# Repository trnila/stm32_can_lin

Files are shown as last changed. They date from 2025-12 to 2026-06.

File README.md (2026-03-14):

# STM32 Triple CAN/LIN USB bridge
STM32G4xx firmware written in Rust using the Embassy framework that bridges CAN-FD buses to Linux via USB using the `gs_usb` driver and socketCAN interface.

- 3x CAN-FD channels
    - configurable 120Ω termination resistor

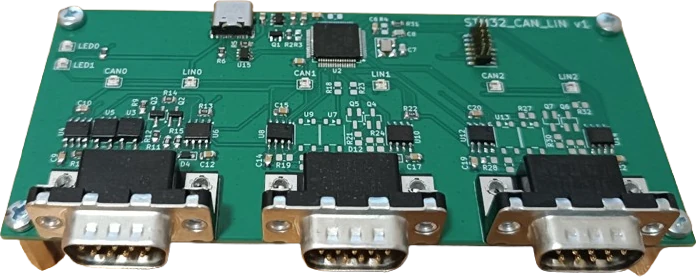
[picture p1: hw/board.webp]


## Build & flash & run
Install Rust via [rustup.rs](https://rustup.rs/).

Set `nSWBOOT0` to 0 using STM32CubeProgrammer for the first time, then connect the debugger and flash the device:
```sh
$ cargo run --release
```

Three socketCAN interfaces will appear, for example as `can0`, `can1`, and `can2`.
You can configure them using `ip` command:
```sh
$ sudo ip link set can0 type can bitrate 500000
$ sudo ip link set can0 up
```

After that, you can start sending and receiving CAN frames:
```sh
$ candump can0
$ cansend can0 123#abcd
```

## Configuration
All configurations must be done while the interface is in the `down` state.
```sh
$ sudo ip link set can0 down
```
After the configuration, bring the interface `up`.

### CAN-FD mode and data bitrate
Set CAN to 500 Kbps and CAN-FD to 1 Mbps:
```sh
$ sudo ip link set can0 type can bitrate 500000 fd on dbitrate 1000000
```

### 120Ω termination resistor
Termination resistor can be enabled in configuration mode via:
```sh
$ sudo ip link set can0 down
$ sudo ip link set can0 type can bitrate 500000 termination 120
$ sudo ip link set can0 up
```

### Persistent interface names
Configure udev rules (`/etc/udev/rules.d/91-scan.rules`) for persistent interface names:
```
SUBSYSTEM=="net", ENV{ID_SERIAL}=="trnila_STM32_CAN_LIN_1", ATTR{dev_id}=="0x0", NAME="scan0"
SUBSYSTEM=="net", ENV{ID_SERIAL}=="trnila_STM32_CAN_LIN_1", ATTR{dev_id}=="0x1", NAME="scan1"
SUBSYSTEM=="net", ENV{ID_SERIAL}=="trnila_STM32_CAN_LIN_1", ATTR{dev_id}=="0x2", NAME="scan2"
```
and then reload `sudo udevadm control --reload-rules` and re-plug the device.

## Test
Install following dependencies:
- uv
- [can-utils](https://github.com/linux-can/can-utils)

Next, connect the DUT's `can0` interface to the tester's `can1_0` interface, and so on. Then run:
```sh
$ CAN_IFACES=0:can0:can1_0,1:can1:can1_1,2:can2:can0_0 ./hw_test.py
```

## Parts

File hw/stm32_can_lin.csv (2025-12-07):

Reference | Qty | Value | DNP | Exclude from BOM | Exclude from Board | manf#
C1 | 1 | 10uF
C2,C4,C5 | 3 | 1uF
C3,C6,C9,C10,C12,C14,C15,C17,C19,C20,C22,C24 | 12 | 100nF
C7,C8 | 2 | 9pF
C11,C16,C21 | 3 | 4.7nF
C13,C18,C23 | 3 | 1nF | DNP
D1,D2,D6,D7,D8,D9,D13,D14 | 8 | WS2812B-2020 |  |  |  | WS2812B-2020
D3,D10,D15 | 3 | NUP2105L |  |  |  | NUP2105L
D4,D11,D16 | 3 | D |  |  |  | BAS321,115
D5,D12,D17 | 3 | ESD1LIN24 |  |  |  | ESD1LIN24
H1,H2,H3,H4 | 4 | MountingHole |  | Excluded from BOM
J1 | 1 | USB_C_Receptacle_USB2.0_16P |  |  |  | USB4105-GF-A-120
J2 | 1 | STM32 SWD |  |  |  | FTSH-107-01-L-DV-K-A-P-TR
J3,J4,J5 | 3 | DE9_Pins_MountingHoles |  |  |  | LD09P33E4GX00LF
Q1 | 1 | BSS123 |  |  |  | BSS123
Q2,Q4,Q6 | 3 | YJL2301F |  |  |  | YJL2301F
Q3,Q5,Q7 | 3 | MMBT2222A |  |  |  | MMBT2222A
R1,R2,R11,R20,R29 | 5 | 10k
R3,R13,R22,R31 | 4 | 47k
R4 | 1 | 10k | DNP
R5,R6 | 2 | 5.1k
R8,R10,R17,R19,R26,R28 | 6 | 56R
R9,R18,R27 | 3 | 6k8
R12,R21,R30 | 3 | 120R
R14,R23,R32 | 3 | 3k3
R15,R24,R33 | 3 | 1k
U1 | 1 | AP2112K-3.3 |  |  |  | AP2112K-3.3TRG1
U2 | 1 | STM32G474RETx |  |  |  | STM32G474RET6
U3,U5,U7,U9,U11,U13 | 6 | EPR411A064000EZ |  |  |  | EPR411A064000EZ
U4,U8,U12 | 3 | MCP2542FDxMF |  |  |  | MCP2542FD-E/SN
U6,U10,U14 | 3 | TJA1021xT |  |  |  | TJA1021T/20/C,118
U15 | 1 | USBLC6-2SC6 |  |  |  | USBLC6-2SC6
Y1 | 1 | 24Mhz |  |  |  | WTL3M23500RH

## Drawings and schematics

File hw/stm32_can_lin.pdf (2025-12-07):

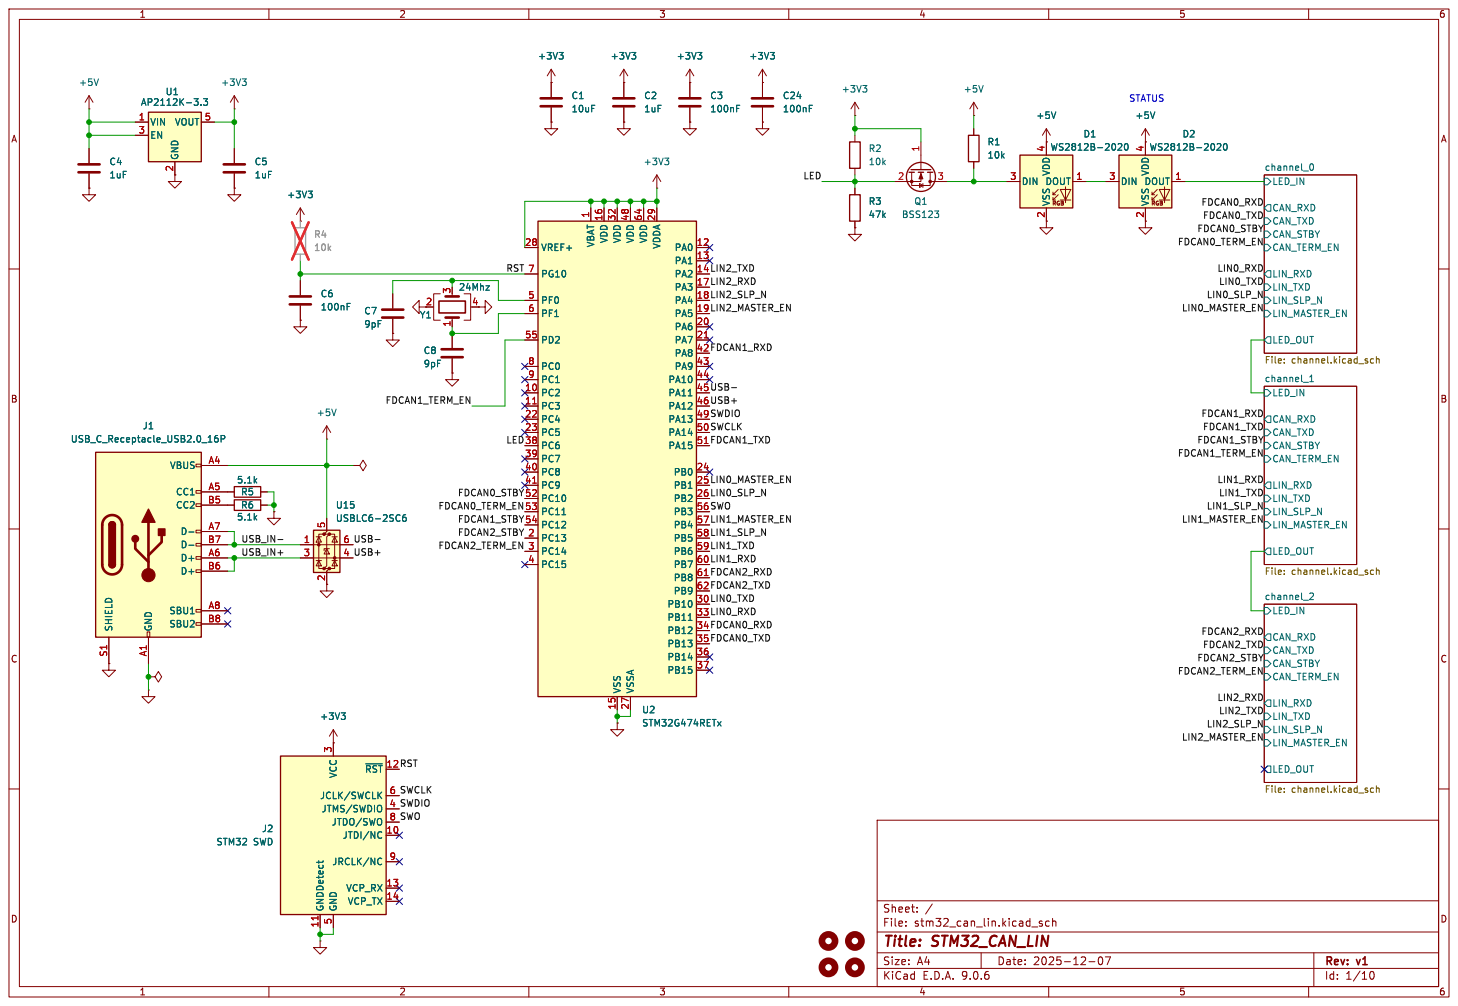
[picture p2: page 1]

1 VDD 16 VDD 32 VSS 15 VDD 48 VSSA 27 VDD 64 VDDA 29 PA0 12 PA1 13 PA2 14 PA3 17 PA4 18 PA5 19 PA6 20 PA7 21 PA8 42 PA9 43 PA10 44 PA11 45 PA12 46 PA13 49 PA14 50 PA15 51 PB0 24 PB1 25 PB2 26 PB3 56 PB4 57 PB5 58 PB6 59 PB7 60 PB8 61 PB9 62 PB10 30 PB11 33 PB12 34 PB13 35 PB14 36 PB15 37 U2STM32G474RETx

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

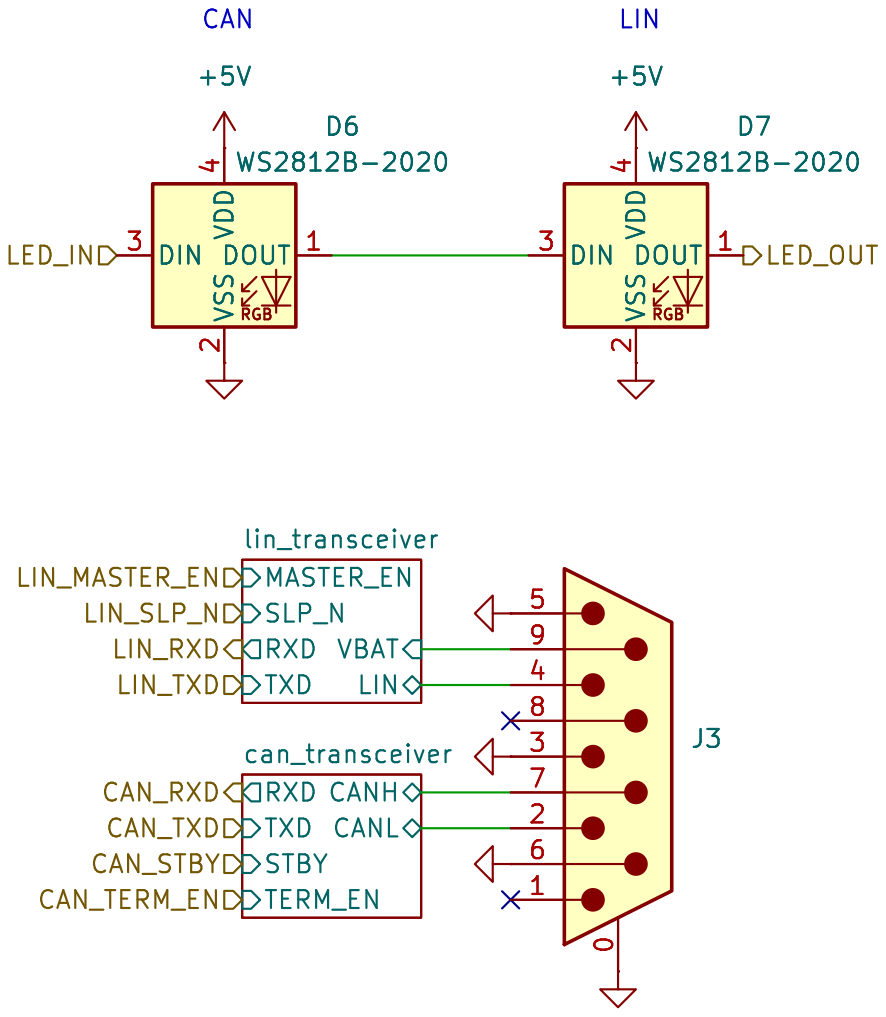
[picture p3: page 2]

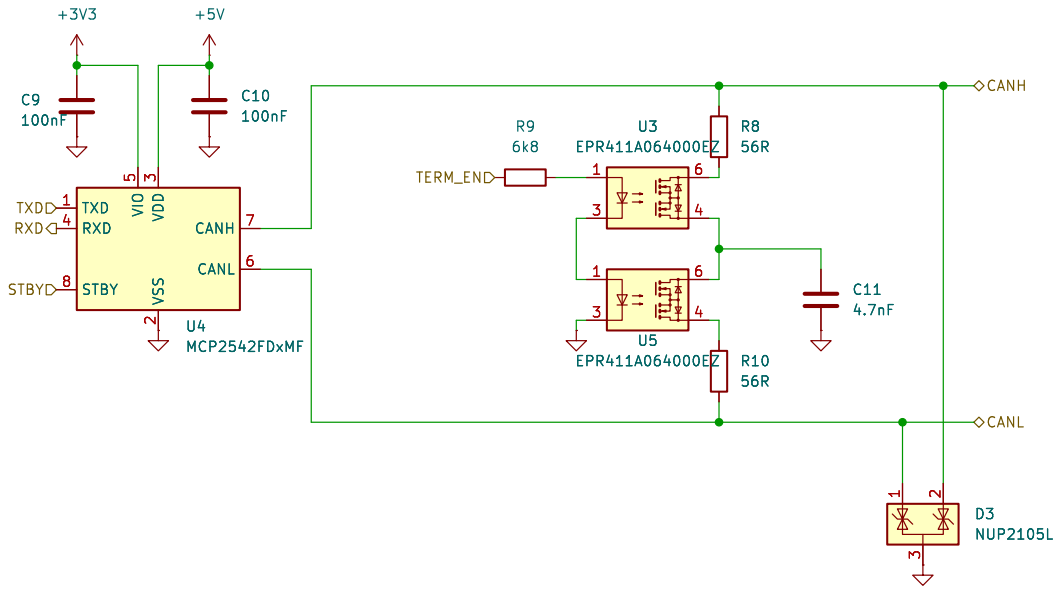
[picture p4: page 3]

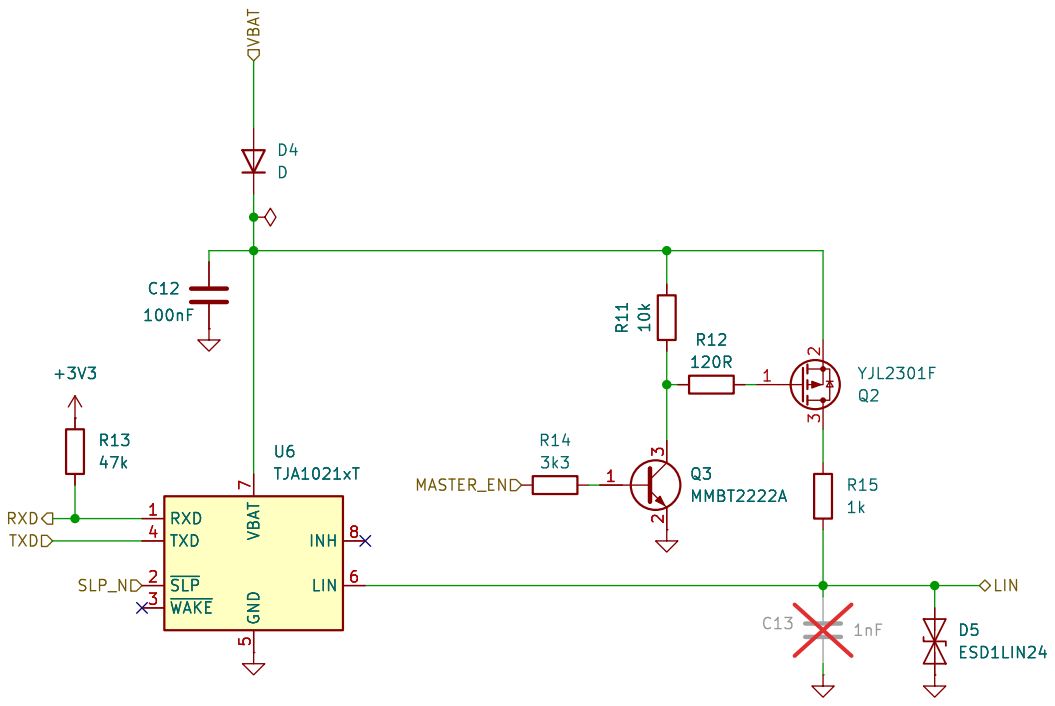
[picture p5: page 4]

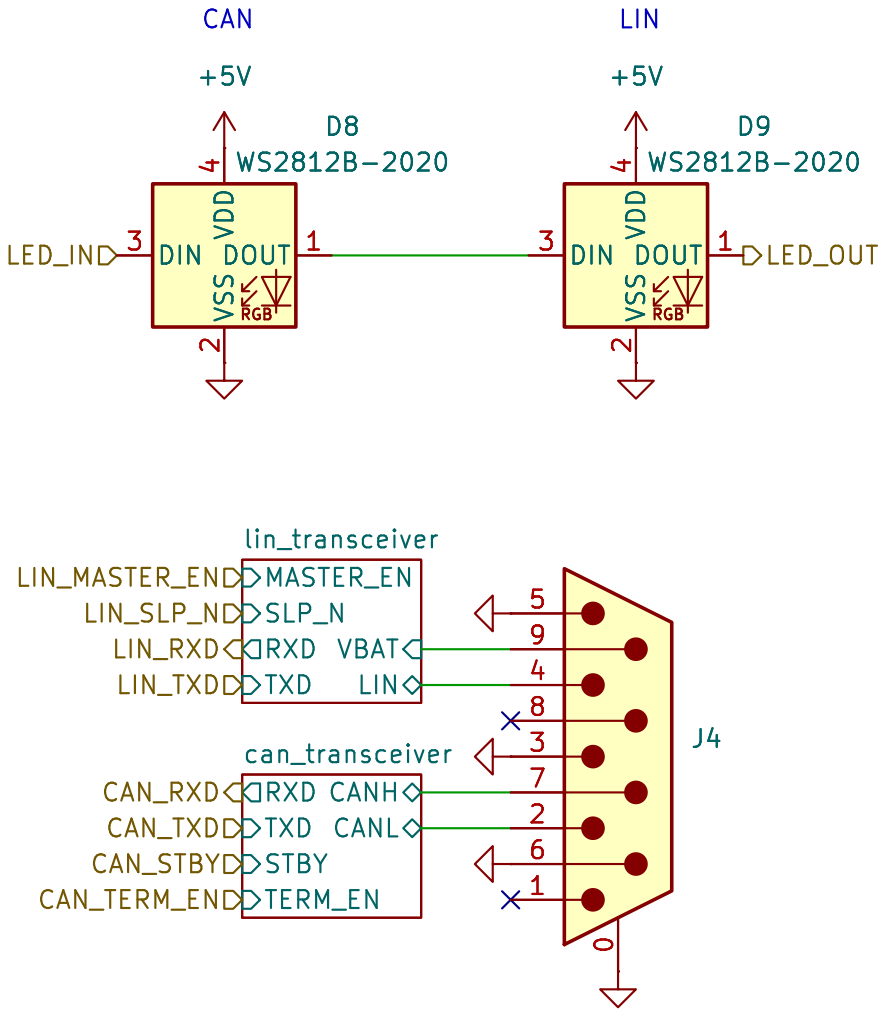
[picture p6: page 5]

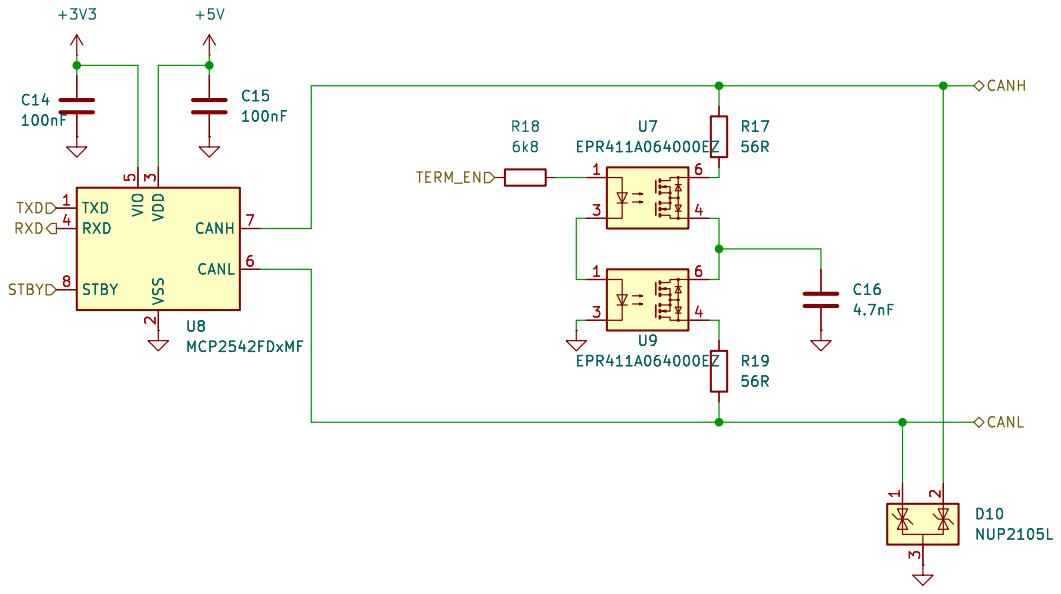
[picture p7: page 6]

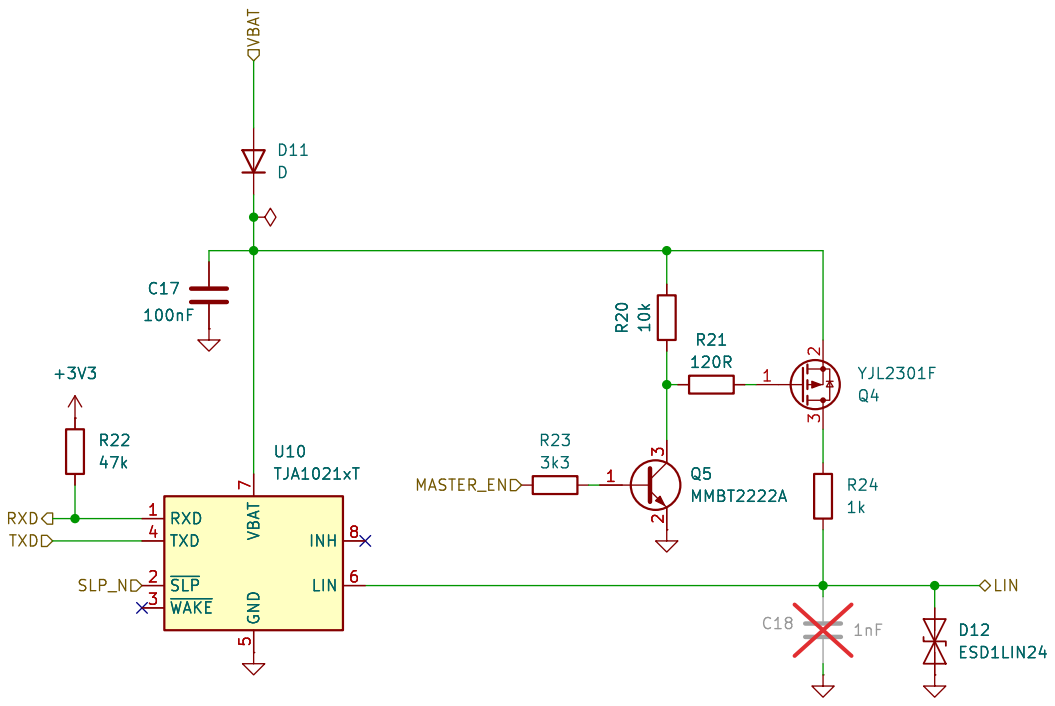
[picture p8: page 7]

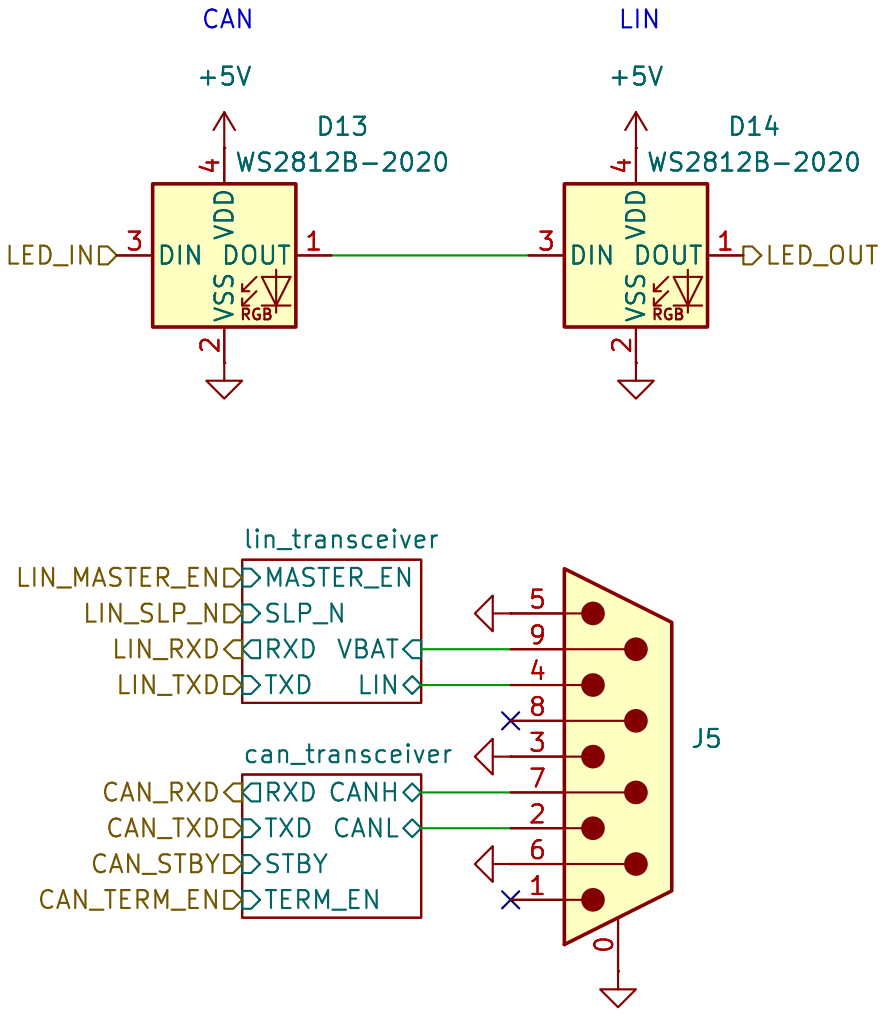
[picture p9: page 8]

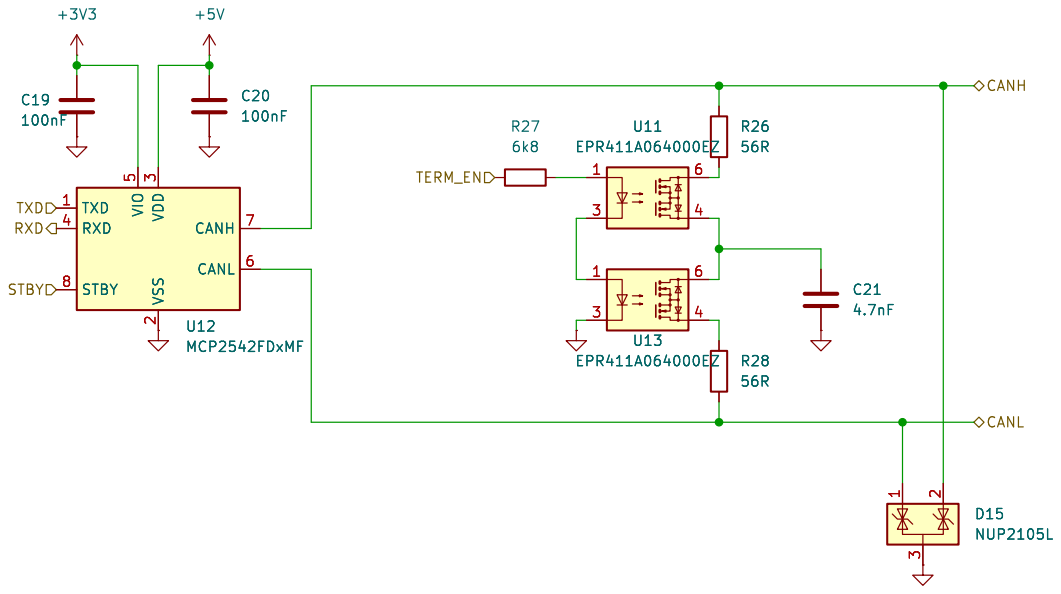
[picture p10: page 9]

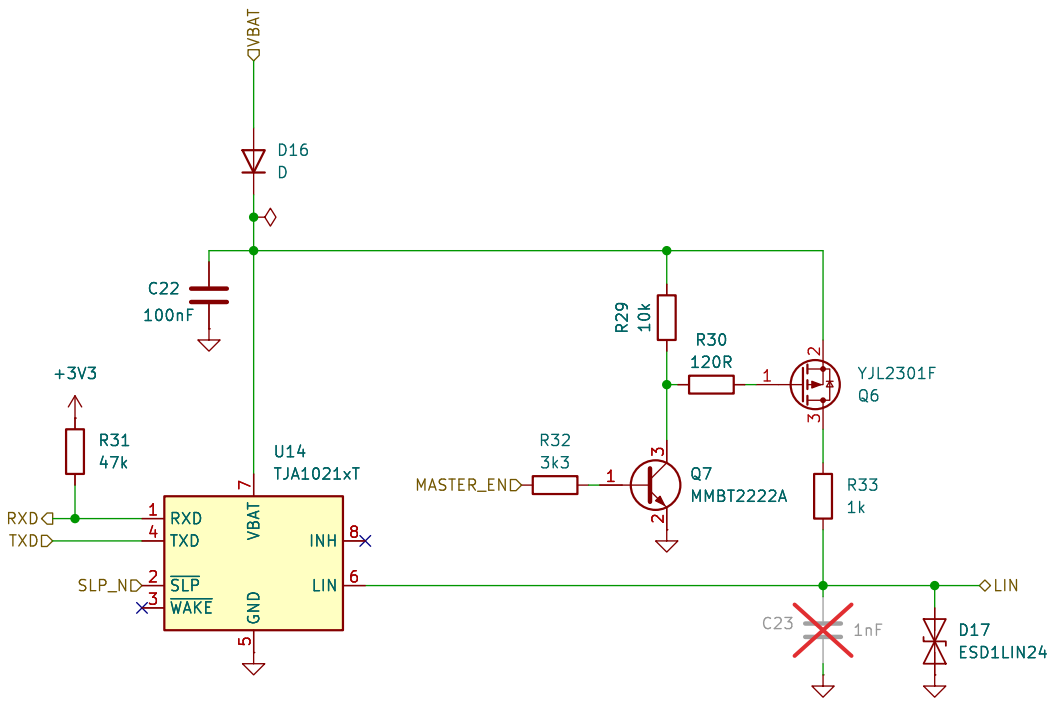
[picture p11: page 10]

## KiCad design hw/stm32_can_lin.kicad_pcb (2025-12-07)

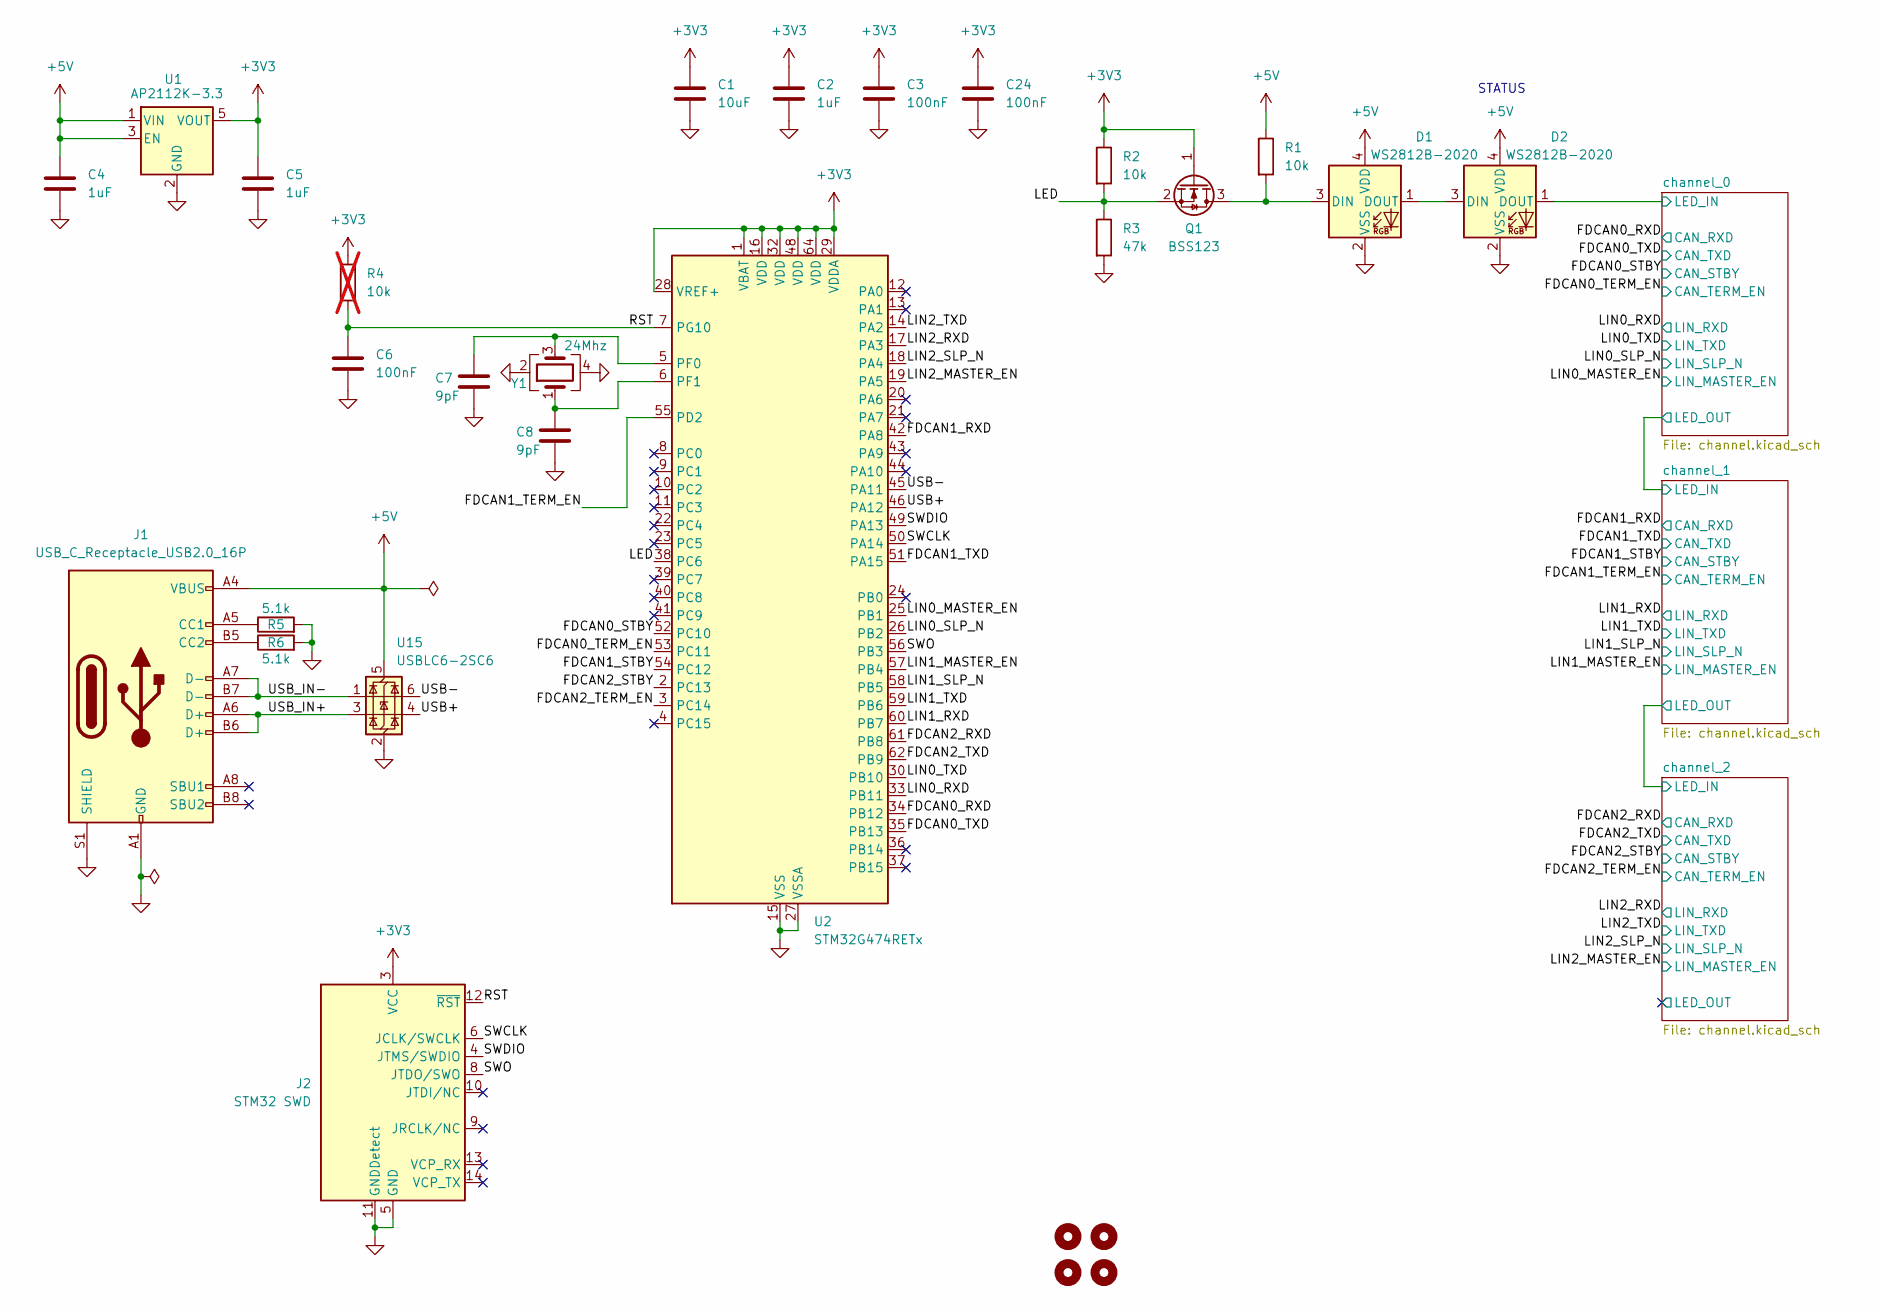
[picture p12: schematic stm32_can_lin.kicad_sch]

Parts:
C1: 10uF; C_0805_2012Metric_Pad1.18x1.45mm_HandSolder
C2, C4, C5: 1uF; C_0805_2012Metric_Pad1.18x1.45mm_HandSolder
C3, C6, C24: 100nF; C_0805_2012Metric_Pad1.18x1.45mm_HandSolder
C7, C8: 9pF; C_0805_2012Metric_Pad1.18x1.45mm_HandSolder
D1, D2: WS2812B-2020; LED_WS2812B-2020_PLCC4_2.0x2.0mm
H1, H2, H3, H4: MountingHole; MountingHole_3.2mm_M3
J1: USB_C_Receptacle_USB2.0_16P; USB_C_Receptacle_GCT_USB4105-xx-A_16P_TopMnt_Horizontal
J2: STM32 SWD; PinHeader_2x07_P1.27mm_Vertical_SMD
Q1: BSS123; SOT-23
R1, R2: 10k; R_0805_2012Metric_Pad1.20x1.40mm_HandSolder
R3: 47k; R_0805_2012Metric_Pad1.20x1.40mm_HandSolder
R4: 10k; R_0805_2012Metric_Pad1.20x1.40mm_HandSolder; not fitted
R5, R6: 5.1k; R_0805_2012Metric_Pad1.20x1.40mm_HandSolder
U1: AP2112K-3.3; SOT-23-5
U2: STM32G474RETx; LQFP-64_10x10mm_P0.5mm
U15: USBLC6-2SC6; SOT-23-6
Y1: 24Mhz; Crystal_SMD_3225-4Pin_3.2x2.5mm_HandSoldering

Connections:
+3V3: C1.1, C2.1, C3.1, C5.1, C24.1, J2.3 (VCC), Q1.1 (G), R2.1, R4.1, U1.5 (VOUT), U2.1 (VBAT), U2.16 (VDD), U2.28 (VREF+), U2.29 (VDDA), U2.32 (VDD), U2.48 (VDD), U2.64 (VDD); also elsewhere on the board
+5V: C4.1, D1.4 (VDD), D2.4 (VDD), J1.A4 (VBUS), J1.A9 (VBUS), J1.B4 (VBUS), J1.B9 (VBUS), R1.1, U1.1 (VIN), U1.3 (EN), U15.5 (VBUS); also elsewhere on the board
/FDCAN0_RXD: U2.34 (PB12); also elsewhere on the board
/FDCAN0_STBY: U2.52 (PC10); also elsewhere on the board
/FDCAN0_TERM_EN: U2.53 (PC11); also elsewhere on the board
/FDCAN0_TXD: U2.35 (PB13); also elsewhere on the board
/FDCAN1_RXD: U2.42 (PA8); also elsewhere on the board
/FDCAN1_STBY: U2.54 (PC12); also elsewhere on the board
/FDCAN1_TERM_EN: U2.55 (PD2); also elsewhere on the board
/FDCAN1_TXD: U2.51 (PA15); also elsewhere on the board
/FDCAN2_RXD: U2.61 (PB8); also elsewhere on the board
/FDCAN2_STBY: U2.2 (PC13); also elsewhere on the board
/FDCAN2_TERM_EN: U2.3 (PC14); also elsewhere on the board
/FDCAN2_TXD: U2.62 (PB9); also elsewhere on the board
/LED: Q1.2 (S), R2.2, R3.1, U2.38 (PC6)
/LIN0_MASTER_EN: U2.25 (PB1); also elsewhere on the board
/LIN0_RXD: U2.33 (PB11); also elsewhere on the board
/LIN0_SLP_N: U2.26 (PB2); also elsewhere on the board
/LIN0_TXD: U2.30 (PB10); also elsewhere on the board
/LIN1_MASTER_EN: U2.57 (PB4); also elsewhere on the board
/LIN1_RXD: U2.60 (PB7); also elsewhere on the board
/LIN1_SLP_N: U2.58 (PB5); also elsewhere on the board
/LIN1_TXD: U2.59 (PB6); also elsewhere on the board
/LIN2_MASTER_EN: U2.19 (PA5); also elsewhere on the board
/LIN2_RXD: U2.17 (PA3); also elsewhere on the board
/LIN2_SLP_N: U2.18 (PA4); also elsewhere on the board
/LIN2_TXD: U2.14 (PA2); also elsewhere on the board
/RST: C6.1, J2.12 (~RST), R4.2, U2.7 (PG10)
/SWCLK: J2.6 (JCLK/SWCLK), U2.50 (PA14)
/SWDIO: J2.4 (JTMS/SWDIO), U2.49 (PA13)
/SWO: J2.8 (JTDO/SWO), U2.56 (PB3)
/USB+: U2.46 (PA12), U15.4 (I/O2)
/USB-: U2.45 (PA11), U15.6 (I/O1)
/USB_IN+: J1.A6 (D+), J1.B6 (D+), U15.3 (I/O2)
/USB_IN-: J1.A7 (D-), J1.B7 (D-), U15.1 (I/O1)
/channel_0/LED_IN: D2.1 (DOUT); also elsewhere on the board
GND: C1.2, C2.2, C3.2, C4.2, C5.2, C6.2, C7.1, C8.1, C24.2, D1.2 (VSS), D2.2 (VSS), J1.A1 (GND), J1.A12 (GND), J1.B1 (GND), J1.B12 (GND), J1.S1 (SHIELD), J2.5 (GND), J2.7 (GND), J2.11 (GNDDetect), R3.2, R5.2, R6.2, U1.2 (GND), U2.15 (VSS), U2.27 (VSSA), U2.31 (VSS), U2.47 (VSS), U2.63 (VSS), U15.2 (GND), Y1.2, Y1.4; also elsewhere on the board
unnamed: D1.3 (DIN), Q1.3 (D), R1.2
unnamed: D1.1 (DOUT), D2.3 (DIN)
unnamed: J1.A5 (CC1), R5.1
unnamed: J1.B5 (CC2), R6.1
unnamed: C7.2, U2.5 (PF0), Y1.3
unnamed: C8.2, U2.6 (PF1), Y1.1

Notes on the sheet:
STATUS

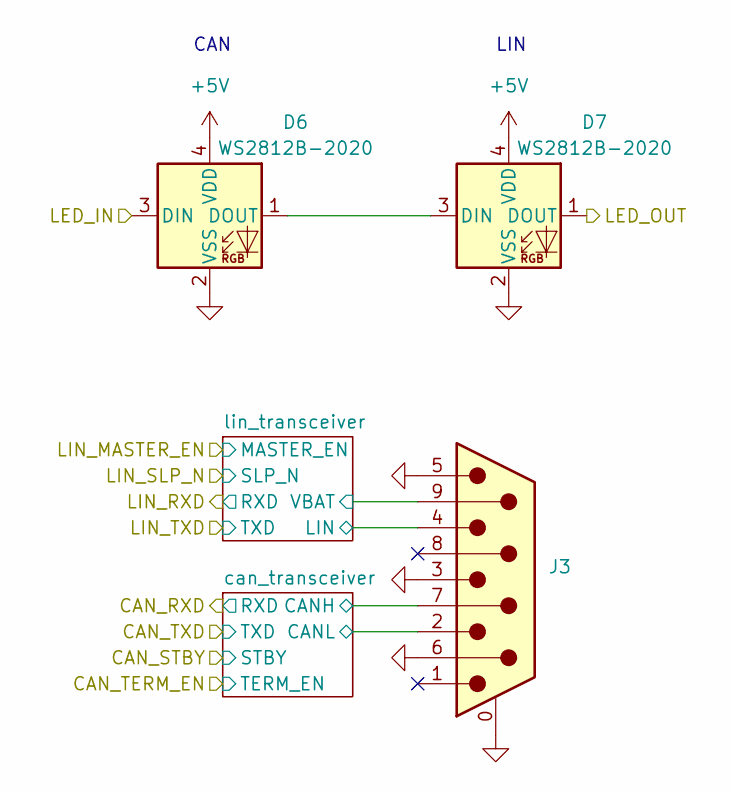
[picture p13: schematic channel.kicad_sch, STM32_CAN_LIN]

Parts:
D6, D7: WS2812B-2020; LED_WS2812B-2020_PLCC4_2.0x2.0mm
J3: DE9_Pins_MountingHoles; DSUB-9_Pins_Horizontal_P2.77x2.84mm_EdgePinOffset7.70mm_Hou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

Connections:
+5V: D6.4 (VDD), D7.4 (VDD); also elsewhere on the board
/channel_0/LED_IN: D6.3 (DIN); also elsewhere on the board
/channel_0/LED_OUT: D7.1 (DOUT); also elsewhere on the board
/channel_0/can_transceiver/CANH: J3.7; also elsewhere on the board
/channel_0/can_transceiver/CANL: J3.2; also elsewhere on the board
/channel_0/lin_transceiver/LIN: J3.4; also elsewhere on the board
/channel_0/lin_transceiver/VBAT: J3.9; also elsewhere on the board
GND: D6.2 (VSS), D7.2 (VSS), J3.0 (PAD), J3.3, J3.5, J3.6; also elsewhere on the board
unnamed: D6.1 (DOUT), D7.3 (DIN)

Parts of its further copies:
D8, D9, D13, D14: WS2812B-2020; LED_WS2812B-2020_PLCC4_2.0x2.0mm
J4, J5: DE9_Pins_MountingHoles; DSUB-9_Pins_Horizontal_P2.77x2.84mm_EdgePinOffset7.70mm_Hou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

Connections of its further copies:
+5V: D8.4 (VDD), D9.4 (VDD), D13.4 (VDD), D14.4 (VDD); also elsewhere on the board
/channel_0/LED_OUT: D8.3 (DIN); also elsewhere on the board
/channel_1/LED_OUT: D9.1 (DOUT), D13.3 (DIN)
/channel_1/can_transceiver/CANH: J4.7; also elsewhere on the board
/channel_1/can_transceiver/CANL: J4.2; also elsewhere on the board
/channel_1/lin_transceiver/LIN: J4.4; also elsewhere on the board
/channel_1/lin_transceiver/VBAT: J4.9; also elsewhere on the board
/channel_2/LED_OUT: D14.1 (DOUT)
/channel_2/can_transceiver/CANH: J5.7; also elsewhere on the board
/channel_2/can_transceiver/CANL: J5.2; also elsewhere on the board
/channel_2/lin_transceiver/LIN: J5.4; also elsewhere on the board
/channel_2/lin_transceiver/VBAT: J5.9; also elsewhere on the board
GND: D8.2 (VSS), D9.2 (VSS), D13.2 (VSS), D14.2 (VSS), J4.0 (PAD), J4.3, J4.5, J4.6, J5.0 (PAD), J5.3, J5.5, J5.6; also elsewhere on the board
unnamed: D8.1 (DOUT), D9.3 (DIN)
unnamed: D13.1 (DOUT), D14.3 (DIN)

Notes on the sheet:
CAN
LIN

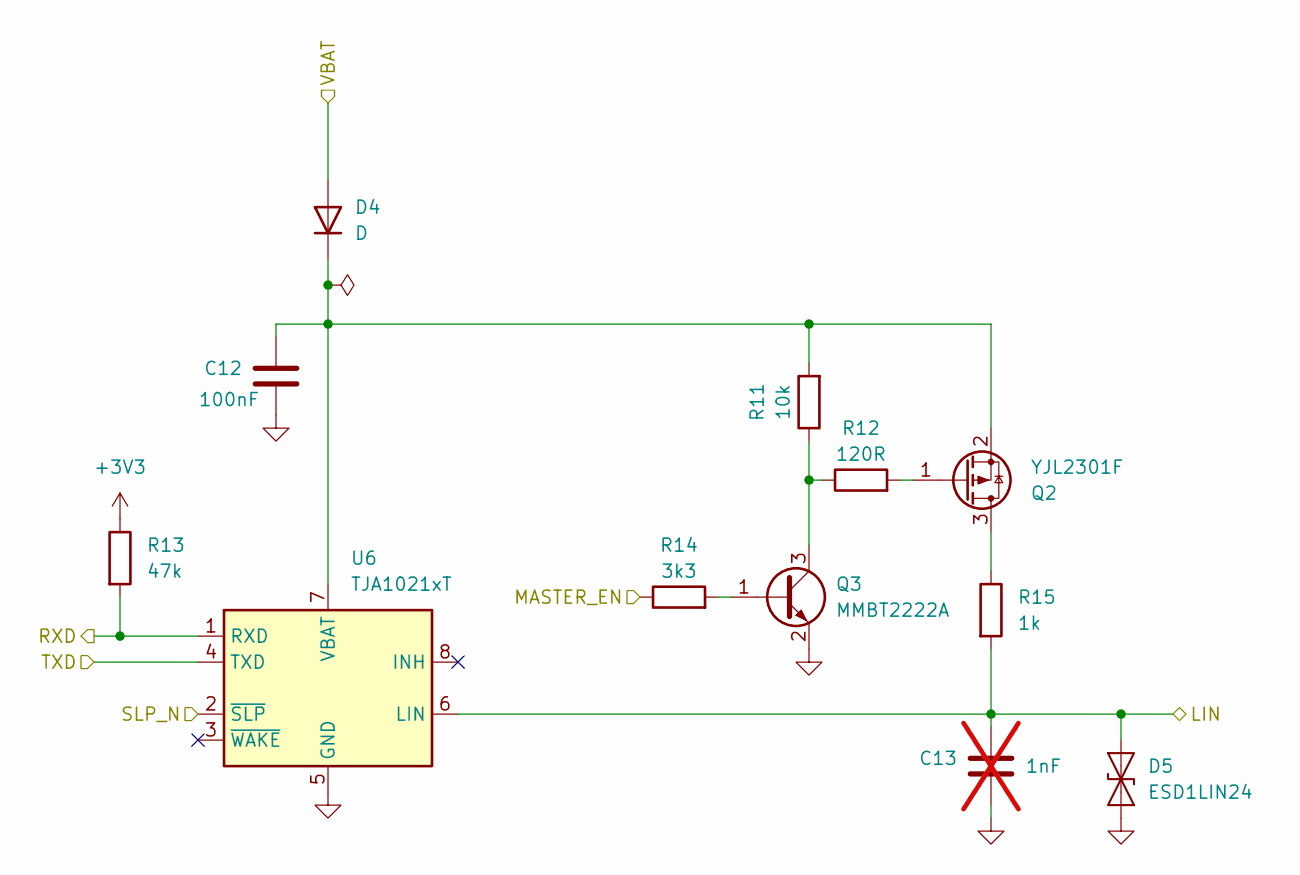
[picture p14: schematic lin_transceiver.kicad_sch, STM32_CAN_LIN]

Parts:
C12: 100nF; C_0805_2012Metric_Pad1.18x1.45mm_HandSolder
C13: 1nF; C_0805_2012Metric_Pad1.18x1.45mm_HandSolder; not fitted
D4: D; D_SOD-323_HandSoldering
D5: ESD1LIN24; D_SOD-923
Q2: YJL2301F; SOT-23_Handsoldering
Q3: MMBT2222A; SOT-23_Handsoldering
R11: 10k; R_0805_2012Metric_Pad1.20x1.40mm_HandSolder
R12: 120R; R_0805_2012Metric_Pad1.20x1.40mm_HandSolder
R13: 47k; R_0805_2012Metric_Pad1.20x1.40mm_HandSolder
R14: 3k3; R_0805_2012Metric_Pad1.20x1.40mm_HandSolder
R15: 1k; R_0805_2012Metric_Pad1.20x1.40mm_HandSolder
U6: TJA1021xT; SOIC-8_3.9x4.9mm_P1.27mm

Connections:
+3V3: R13.1; also elsewhere on the board
/LIN0_MASTER_EN: R14.1; also elsewhere on the board
/LIN0_RXD: R13.2, U6.1 (RXD); also elsewhere on the board
/LIN0_SLP_N: U6.2 (~SLP); also elsewhere on the board
/LIN0_TXD: U6.4 (TXD); also elsewhere on the board
/channel_0/lin_transceiver/LIN: C13.1, D5.2 (A2), R15.2, U6.6 (LIN); also elsewhere on the board
/channel_0/lin_transceiver/VBAT: D4.2 (A); also elsewhere on the board
GND: C12.2, C13.2, D5.1 (A1), Q3.2 (E), U6.5 (GND); also elsewhere on the board
unnamed: C12.1, D4.1 (K), Q2.2 (S), R11.2, U6.7 (VBAT)
unnamed: Q2.3 (D), R15.1
unnamed: Q2.1 (G), R12.2
unnamed: Q3.1 (B), R14.2
unnamed: Q3.3 (C), R11.1, R12.1

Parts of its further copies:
C17, C22: 100nF; C_0805_2012Metric_Pad1.18x1.45mm_HandSolder
C18, C23: 1nF; C_0805_2012Metric_Pad1.18x1.45mm_HandSolder; not fitted
D11, D16: D; D_SOD-323_HandSoldering
D12, D17: ESD1LIN24; D_SOD-923
Q4, Q6: YJL2301F; SOT-23_Handsoldering
Q5, Q7: MMBT2222A; SOT-23_Handsoldering
R20, R29: 10k; R_0805_2012Metric_Pad1.20x1.40mm_HandSolder
R21, R30: 120R; R_0805_2012Metric_Pad1.20x1.40mm_HandSolder
R22, R31: 47k; R_0805_2012Metric_Pad1.20x1.40mm_HandSolder
R23, R32: 3k3; R_0805_2012Metric_Pad1.20x1.40mm_HandSolder
R24, R33: 1k; R_0805_2012Metric_Pad1.20x1.40mm_HandSolder
U10, U14: TJA1021xT; SOIC-8_3.9x4.9mm_P1.27mm

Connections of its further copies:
+3V3: R22.1, R31.1; also elsewhere on the board
/LIN1_MASTER_EN: R23.1; also elsewhere on the board
/LIN1_RXD: R22.2, U10.1 (RXD); also elsewhere on the board
/LIN1_SLP_N: U10.2 (~SLP); also elsewhere on the board
/LIN1_TXD: U10.4 (TXD); also elsewhere on the board
/LIN2_MASTER_EN: R32.1; also elsewhere on the board
/LIN2_RXD: R31.2, U14.1 (RXD); also elsewhere on the board
/LIN2_SLP_N: U14.2 (~SLP); also elsewhere on the board
/LIN2_TXD: U14.4 (TXD); also elsewhere on the board
/channel_1/lin_transceiver/LIN: C18.1, D12.2 (A2), R24.2, U10.6 (LIN); also elsewhere on the board
/channel_1/lin_transceiver/VBAT: D11.2 (A); also elsewhere on the board
/channel_2/lin_transceiver/LIN: C23.1, D17.2 (A2), R33.2, U14.6 (LIN); also elsewhere on the board
/channel_2/lin_transceiver/VBAT: D16.2 (A); also elsewhere on the board
GND: C17.2, C18.2, C22.2, C23.2, D12.1 (A1), D17.1 (A1), Q5.2 (E), Q7.2 (E), U10.5 (GND), U14.5 (GND); also elsewhere on the board
unnamed: C17.1, D11.1 (K), Q4.2 (S), R20.2, U10.7 (VBAT)
unnamed: C22.1, D16.1 (K), Q6.2 (S), R29.2, U14.7 (VBAT)
unnamed: Q4.3 (D), R24.1
unnamed: Q4.1 (G), R21.2
unnamed: Q5.1 (B), R23.2
unnamed: Q5.3 (C), R20.1, R21.1
unnamed: Q6.3 (D), R33.1
unnamed: Q6.1 (G), R30.2
unnamed: Q7.1 (B), R32.2
unnamed: Q7.3 (C), R29.1, R30.1

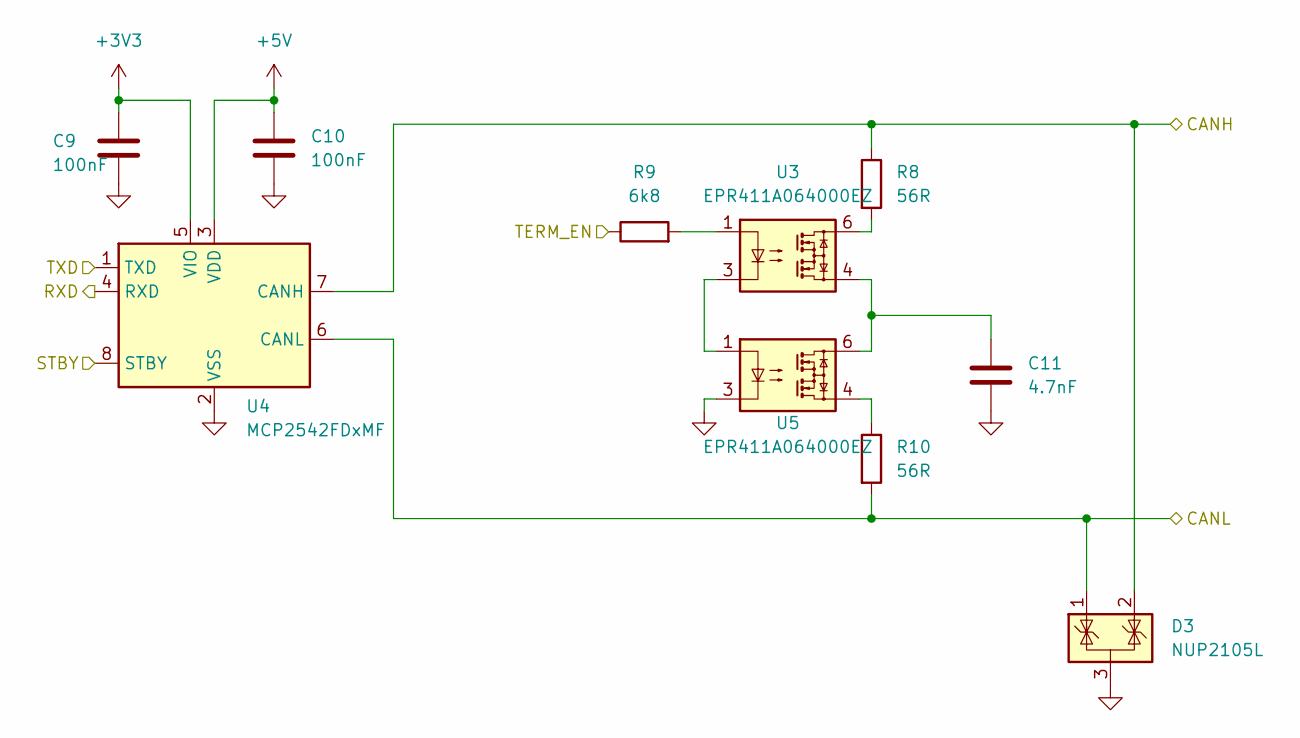
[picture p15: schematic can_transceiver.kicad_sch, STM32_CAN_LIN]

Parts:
C9, C10: 100nF; C_0805_2012Metric_Pad1.18x1.45mm_HandSolder
C11: 4.7nF; C_0805_2012Metric_Pad1.18x1.45mm_HandSolder
D3: NUP2105L; SOT-23
R8, R10: 56R; R_0805_2012Metric_Pad1.20x1.40mm_HandSolder
R9: 6k8; R_0805_2012Metric_Pad1.20x1.40mm_HandSolder
U3, U5: EPR411A064000EZ; SOIC-4_4.7_4.4_P2.54
U4: MCP2542FDxMF; SOIC-8_3.9x4.9mm_P1.27mm

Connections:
+3V3: C9.1, U4.5 (VIO); also elsewhere on the board
+5V: C10.1, U4.3 (VDD); also elsewhere on the board
/FDCAN0_RXD: U4.4 (RXD); also elsewhere on the board
/FDCAN0_STBY: U4.8 (STBY); also elsewhere on the board
/FDCAN0_TERM_EN: R9.1; also elsewhere on the board
/FDCAN0_TXD: U4.1 (TXD); also elsewhere on the board
/channel_0/can_transceiver/CANH: D3.2 (K), R8.1, U4.7 (CANH); also elsewhere on the board
/channel_0/can_transceiver/CANL: D3.1 (K), R10.2, U4.6 (CANL); also elsewhere on the board
GND: C9.2, C10.2, C11.2, D3.3 (A), U4.2 (VSS), U5.3; also elsewhere on the board
unnamed: C11.1, U3.4, U5.6
unnamed: R8.2, U3.6
unnamed: R9.2, U3.1
unnamed: R10.1, U5.4
unnamed: U3.3, U5.1

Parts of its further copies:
C14, C15, C19, C20: 100nF; C_0805_2012Metric_Pad1.18x1.45mm_HandSolder
C16, C21: 4.7nF; C_0805_2012Metric_Pad1.18x1.45mm_HandSolder
D10, D15: NUP2105L; SOT-23
R17, R19, R26, R28: 56R; R_0805_2012Metric_Pad1.20x1.40mm_HandSolder
R18, R27: 6k8; R_0805_2012Metric_Pad1.20x1.40mm_HandSolder
U7, U9, U11, U13: EPR411A064000EZ; SOIC-4_4.7_4.4_P2.54
U8, U12: MCP2542FDxMF; SOIC-8_3.9x4.9mm_P1.27mm

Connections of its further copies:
+3V3: C14.1, C19.1, U8.5 (VIO), U12.5 (VIO); also elsewhere on the board
+5V: C15.1, C20.1, U8.3 (VDD), U12.3 (VDD); also elsewhere on the board
/FDCAN1_RXD: U8.4 (RXD); also elsewhere on the board
/FDCAN1_STBY: U8.8 (STBY); also elsewhere on the board
/FDCAN1_TERM_EN: R18.1; also elsewhere on the board
/FDCAN1_TXD: U8.1 (TXD); also elsewhere on the board
/FDCAN2_RXD: U12.4 (RXD); also elsewhere on the board
/FDCAN2_STBY: U12.8 (STBY); also elsewhere on the board
/FDCAN2_TERM_EN: R27.1; also elsewhere on the board
/FDCAN2_TXD: U12.1 (TXD); also elsewhere on the board
/channel_1/can_transceiver/CANH: D10.2 (K), R17.1, U8.7 (CANH); also elsewhere on the board
/channel_1/can_transceiver/CANL: D10.1 (K), R19.2, U8.6 (CANL); also elsewhere on the board
/channel_2/can_transceiver/CANH: D15.2 (K), R26.1, U12.7 (CANH); also elsewhere on the board
/channel_2/can_transceiver/CANL: D15.1 (K), R28.2, U12.6 (CANL); also elsewhere on the board
GND: C14.2, C15.2, C16.2, C19.2, C20.2, C21.2, D10.3 (A), D15.3 (A), U8.2 (VSS), U9.3, U12.2 (VSS), U13.3; also elsewhere on the board
unnamed: C16.1, U7.4, U9.6
unnamed: C21.1, U11.4, U13.6
unnamed: R17.2, U7.6
unnamed: R18.2, U7.1
unnamed: R19.1, U9.4
unnamed: R26.2, U11.6
unnamed: R27.2, U11.1
unnamed: R28.1, U13.4
unnamed: U7.3, U9.1
unnamed: U11.3, U13.1

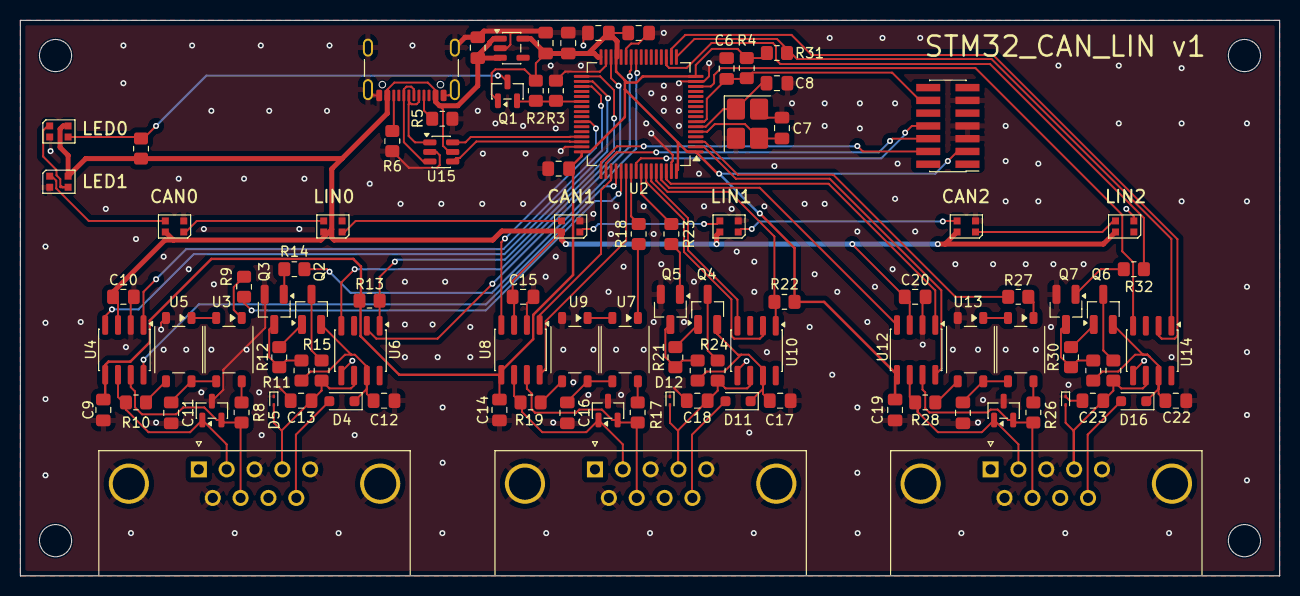
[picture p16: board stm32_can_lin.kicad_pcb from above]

Board: 2 copper layers, 125.2 x 55.2 mm, 103 parts (0 on the bottom side), 90 nets.

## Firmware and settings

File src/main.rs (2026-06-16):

#![no_std]
#![no_main]

use crate::can::can_usb_bridge;
use crate::gs_usb::CHANNEL_QUEUE_SIZE;
use crate::gs_usb::USB_QUEUE_SIZE;
use crate::gs_usb::UsbCommand;
use crate::gs_usb::UsbCommandQueues;
use crate::gs_usb::UsbResponse;
use crate::gs_usb::usb_init;
use embassy_executor::Spawner;
use embassy_stm32::bind_interrupts;
use embassy_stm32::can::CanConfigurator;
use embassy_stm32::gpio::Level;
use embassy_stm32::gpio::Output;
use embassy_stm32::gpio::Speed;
use embassy_stm32::peripherals;
use embassy_stm32::rcc;
use embassy_stm32::time::mhz;
use embassy_stm32::usb::Driver;
use embassy_sync::blocking_mutex::raw::ThreadModeRawMutex;
use embassy_sync::channel::Channel;
use {defmt_rtt as _, panic_probe as _};

mod can;
mod gs_usb;

static USB_CMDS_CH0: Channel<ThreadModeRawMutex, UsbCommand, CHANNEL_QUEUE_SIZE> = Channel::new();
static USB_CMDS_CH1: Channel<ThreadModeRawMutex, UsbCommand, CHANNEL_QUEUE_SIZE> = Channel::new();
static USB_CMDS_CH2: Channel<ThreadModeRawMutex, UsbCommand, CHANNEL_QUEUE_SIZE> = Channel::new();
static USB_RESPS: Channel<ThreadModeRawMutex, UsbResponse, USB_QUEUE_SIZE> = Channel::new();

bind_interrupts!(struct Irqs {
    USB_LP => embassy_stm32::usb::InterruptHandler<peripherals::USB>;
    FDCAN1_IT0 => embassy_stm32::can::IT0InterruptHandler<peripherals::FDCAN1>;
    FDCAN1_IT1 => embassy_stm32::can::IT1InterruptHandler<peripherals::FDCAN1>;
    FDCAN2_IT0 => embassy_stm32::can::IT0InterruptHandler<peripherals::FDCAN2>;
    FDCAN2_IT1 => embassy_stm32::can::IT1InterruptHandler<peripherals::FDCAN2>;
    FDCAN3_IT0 => embassy_stm32::can::IT0InterruptHandler<peripherals::FDCAN3>;
    FDCAN3_IT1 => embassy_stm32::can::IT1InterruptHandler<peripherals::FDCAN3>;
});

#[embassy_executor::main]
async fn main(spawner: Spawner) {
    let p = embassy_stm32::init({
        let mut config = embassy_stm32::Config::default();
        config.rcc.hsi = false;
        config.rcc.hse = Some(rcc::Hse {
            freq: mhz(24),
            mode: rcc::HseMode::Oscillator,
        });
        config.rcc.sys = rcc::Sysclk::Pll1R;
        config.rcc.pll = Some(rcc::Pll {
            source: rcc::PllSource::Hse,
            prediv: rcc::PllPreDiv::Div6,
            mul: rcc::PllMul::Mul85,
            divr: Some(rcc::PllRDiv::Div2),
            divq: Some(rcc::PllQDiv::Div2),
            divp: Some(rcc::PllPDiv::Div2),
        });
        config.rcc.ahb_pre = rcc::AHBPrescaler::Div1;
        config.rcc.apb1_pre = rcc::APBPrescaler::Div2;
        config.rcc.mux.fdcansel = rcc::mux::Fdcansel::Hse;
        config
    });

    // FDCAN0
    spawner.spawn(
        can_usb_bridge(
            0,
            CanConfigurator::new(p.FDCAN2, p.PB12, p.PB13, Irqs),
            Output::new(p.PC10, Level::Low, Speed::Low),
            Output::new(p.PC11, Level::Low, Speed::Low),
            USB_CMDS_CH0.receiver(),
            USB_RESPS.sender(),
        )
        .unwrap(),
    );

    // FDCAN1
    spawner.spawn(
        can_usb_bridge(
            1,
            CanConfigurator::new(p.FDCAN3, p.PA8, p.PA15, Irqs),
            Output::new(p.PC12, Level::Low, Speed::Low),
            Output::new(p.PD2, Level::Low, Speed::Low),
            USB_CMDS_CH1.receiver(),
            USB_RESPS.sender(),
        )
        .unwrap(),
    );

    // FDCAN2
    spawner.spawn(
        can_usb_bridge(
            2,
            CanConfigurator::new(p.FDCAN1, p.PB8, p.PB9, Irqs),
            Output::new(p.PC13, Level::Low, Speed::Low),
            Output::new(p.PC14, Level::Low, Speed::Low),
            USB_CMDS_CH2.receiver(),
            USB_RESPS.sender(),
        )
        .unwrap(),
    );

    let usb = Driver::new(p.USB, Irqs, p.PA12, p.PA11);
    spawner.spawn(
        usb_init(
            usb,
            USB_RESPS.receiver(),
            UsbCommandQueues {
                channel: [
                    USB_CMDS_CH0.sender(),
                    USB_CMDS_CH1.sender(),
                    USB_CMDS_CH2.sender(),
                ],
            },
        )
        .unwrap(),
    );
}

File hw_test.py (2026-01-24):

#!/usr/bin/env -S uv run --script
# /// script
# requires-python = ">=3.10"
# dependencies = [
#     "pytest==9.0.2",
#     "python-can==4.6.1",
# ]
# ///
import subprocess
import pytest
import can
from contextlib import contextmanager
from dataclasses import dataclass, field
from enum import Enum
import os
import itertools


class ChannelRole(Enum):
    RX = "rx"
    TX = "tx"


@dataclass
class DutChannelRole:
    channel: int
    role: ChannelRole


@dataclass
class ChannelInterfaces:
    dut: str
    test: str


@dataclass
class CanBuses:
    rx: can.Bus
    tx: can.Bus


@dataclass
class CanMsgId:
    arbitration_id: int
    is_extended_id: bool


@dataclass
class CanFullDuplexTest:
    """Arguments for canfdtest (CAN Full-Duplex Test) program"""

    description: str
    args: list[str]
    bus_params: dict[str, str] = field(default_factory=dict)


CHANNELS = [0, 1, 2]
ROLES = [ChannelRole.TX, ChannelRole.RX]
ALL_CHANNEL_ROLES = [
    DutChannelRole(chan, role) for chan, role in itertools.product(CHANNELS, ROLES)
]
CAN_FULL_DUPLEX_CONFIGS = [
    CanFullDuplexTest("standard", []),
    CanFullDuplexTest("extended", ["-e"]),
    CanFullDuplexTest("standard-1byte", ["-s", "1"]),
    CanFullDuplexTest("standard-7byte", ["-s", "7"]),
    CanFullDuplexTest("FD", ["-d"], {"dbitrate": "1000000"}),
    CanFullDuplexTest("FD", ["-d"], {"dbitrate": "2000000"}),
]


def open_can(
    iface: str,
    bitrate: int,
    dbitrate: int | None = None,
    termination: bool | None = None,
) -> can.Bus:
    subprocess.check_call(["sudo", "ip", "link", "set", iface, "down"])
    args = []
    if dbitrate:
        args += ["fd", "on", "dbitrate", str(dbitrate)]
    if termination is not None:
        args += ["termination", "120" if termination else "0"]

    subprocess.check_call(
        ["sudo", "ip", "link", "set", iface, "type", "can", "bitrate", str(bitrate)]
        + args
    )
    subprocess.check_call(["sudo", "ip", "link", "set", iface, "up"])
    return can.Bus(interface="socketcan", channel=iface, fd=dbitrate is not None)


def channel_ifaces(channel: int) -> ChannelInterfaces:
    config = os.getenv("CAN_IFACES", "")
    if config:
        for s in config.split(","):
            chan, dut_iface, test_iface = s.split(":")
            if int(chan) == channel:
                return ChannelInterfaces(dut_iface, test_iface)
    pytest.skip(f"CAN channel {channel} not configured")


@contextmanager
def open_buses(
    channel: DutChannelRole, bitrate: int = 500000, dbitrate: int | None = None
):
    chan = channel_ifaces(channel.channel)

    with (
        open_can(chan.dut, bitrate, dbitrate) as bus_a,
        open_can(chan.test, bitrate, dbitrate) as bus_b,
    ):
        if channel.role == ChannelRole.TX:
            yield CanBuses(bus_a, bus_b)
        else:
            yield CanBuses(bus_b, bus_a)


def channel_role_id(channel_role: DutChannelRole) -> str:
    role = "tx" if channel_role.role == ChannelRole.TX else "rx"
    return f"chan{channel_role.channel}-{role}"


@pytest.mark.parametrize("dlc", range(0, 9))
@pytest.mark.parametrize("channel_role", ALL_CHANNEL_ROLES, ids=channel_role_id)
def test_dlc(channel_role: DutChannelRole, dlc: int):
    with open_buses(channel_role) as buses:
        buses.tx.send(
            can.Message(arbitration_id=42, is_extended_id=False, data=range(dlc))
        )
        received = buses.rx.recv(1)
        assert received
        assert received.arbitration_id == 42
        assert not received.is_extended_id
        assert not received.is_fd
        assert list(received.data) == list(range(dlc))


@pytest.mark.parametrize("dlc", [0, 1, 2, 3, 4, 5, 6, 7, 8, 12, 16, 20, 24, 32, 48, 64])
@pytest.mark.parametrize("channel_role", ALL_CHANNEL_ROLES, ids=channel_role_id)
def test_fd_dlc(channel_role: DutChannelRole, dlc: int):
    with open_buses(channel_role, dbitrate=1000000) as buses:
        buses.tx.send(
            can.Message(
                arbitration_id=42,
                is_extended_id=False,
                data=range(dlc),
                is_fd=True,
                bitrate_switch=False,
            )
        )
        received = buses.rx.recv(1)
        assert received
        assert received.arbitration_id == 42
        assert not received.is_extended_id
        assert received.is_fd
        assert list(received.data) == list(range(dlc))


@pytest.mark.parametrize(
    "msgid",
    [
        CanMsgId(0, False),
        CanMsgId(1, True),
        CanMsgId(0x42, True),
        CanMsgId(0x42, False),
        CanMsgId(0x7FF, True),
        CanMsgId(0x7FF, False),
        CanMsgId(0x800, True),
        CanMsgId(0x1FFFFFFF, True),
    ],
    ids=lambda msg: f"0x{msg.arbitration_id:x}-{'extended' if msg.is_extended_id else 'std'}",
)
@pytest.mark.parametrize("channel_role", ALL_CHANNEL_ROLES, ids=channel_role_id)
@pytest.mark.parametrize("fd", [True, False])
def test_msgids(fd: bool, channel_role: DutChannelRole, msgid: CanMsgId):
    with open_buses(channel_role, dbitrate=1_000_000 if fd else None) as buses:
        buses.tx.send(
            can.Message(
                arbitration_id=msgid.arbitration_id,
                is_extended_id=msgid.is_extended_id,
                is_fd=fd,
            )
        )
        received = buses.rx.recv(1)
        assert received
        assert received.arbitration_id == msgid.arbitration_id
        assert received.is_extended_id == msgid.is_extended_id
        assert received.is_fd == fd
        assert received.data == bytearray([])


@pytest.mark.parametrize(
    "bitrate",
    [125000, 250000, 500000, 1000000],
)
@pytest.mark.parametrize("channel_role", ALL_CHANNEL_ROLES, ids=channel_role_id)
def test_bitrates(channel_role: str, bitrate: int):
    with open_buses(channel_role, bitrate) as buses:
        buses.tx.send(can.Message(arbitration_id=0x345, data=[1, 2, 3, 4, 5, 6, 7, 8]))
        received = buses.rx.recv(1)
        assert received.arbitration_id == 0x345
        assert list(received.data) == [1, 2, 3, 4, 5, 6, 7, 8]


@pytest.mark.parametrize("channel", CHANNELS)
def test_termination_conf(channel: int):
    interfaces = channel_ifaces(channel)
    for termination in [True, False, True]:
        with open_can(interfaces.dut, 500000, termination=termination):
            out = subprocess.check_output(
                ["ip", "-detail", "link", "show", interfaces.dut], text=True
            )
            if termination:
                assert "termination 120 " in out
            else:
                assert "termination 0 " in out
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

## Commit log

2025-12-07 HW initial commit v1
    [can_transceiver.kicad_sch, channel.kicad_sch, lin_transceiver.kicad_sch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]
2026-01-03 hw_test.py: canfdtest with extended frames and different payload sizes
2026-01-08 hw: added board photo
2026-01-24 configurable CAN termination resistor
